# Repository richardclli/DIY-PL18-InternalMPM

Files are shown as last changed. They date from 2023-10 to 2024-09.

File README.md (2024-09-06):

# DIY-PL18-InternalMPM
An internal MPM (Multi-Protocol Module) for Flysky PL18 Mod

This internal module works with the modified version of Flysky PL18 that flashes with EdgeTX:

https://github.com/EdgeTX/edgetx/wiki/PL18-Hardware-Mod-for-Complete-EdgeTX-Support

For MPM firmware download, please visit the official page:

https://github.com/pascallanger/DIY-Multiprotocol-TX-Module

## Installation Procedures:
1. Add an antenna to the PL18

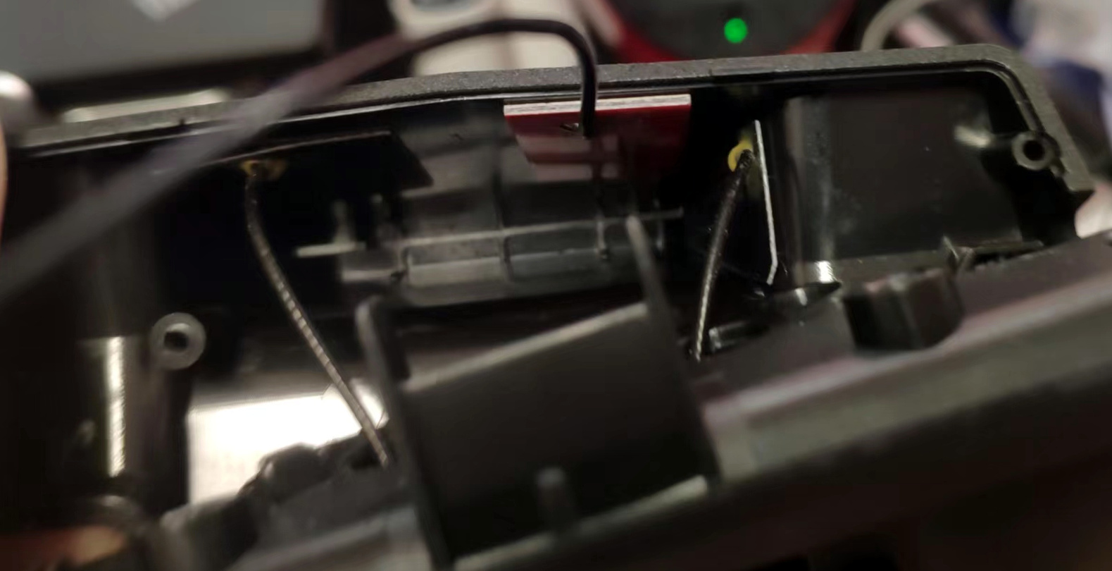
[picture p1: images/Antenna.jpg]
Antanna Installation


2. Solder the power control wire to PI.00 pin

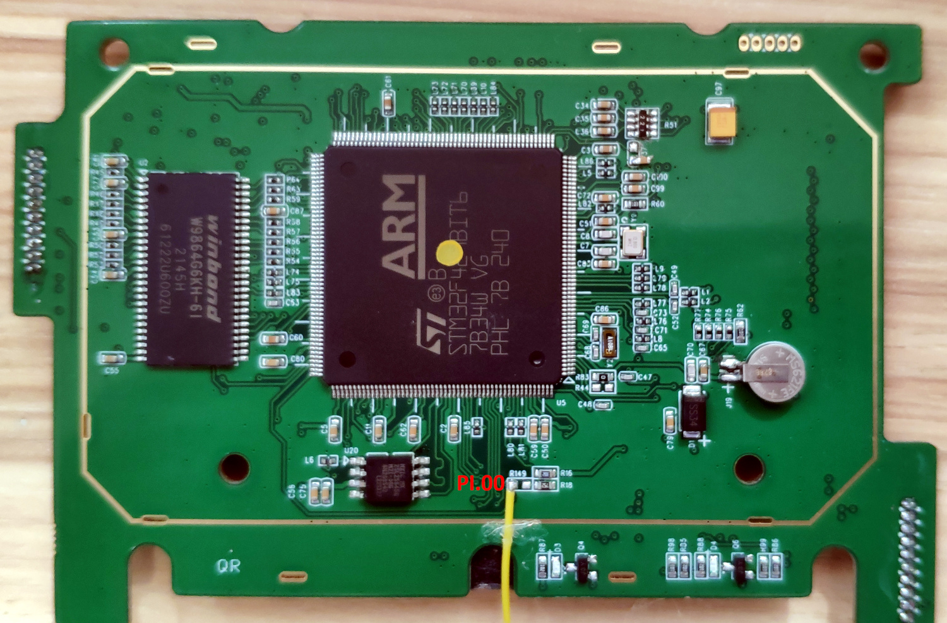
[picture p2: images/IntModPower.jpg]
Add Power Control


3. Install the PCB and insert the power control pin, you may need to use a sticky tape to ensure the MPM PCB is fixed to the PL18 PCB properly.

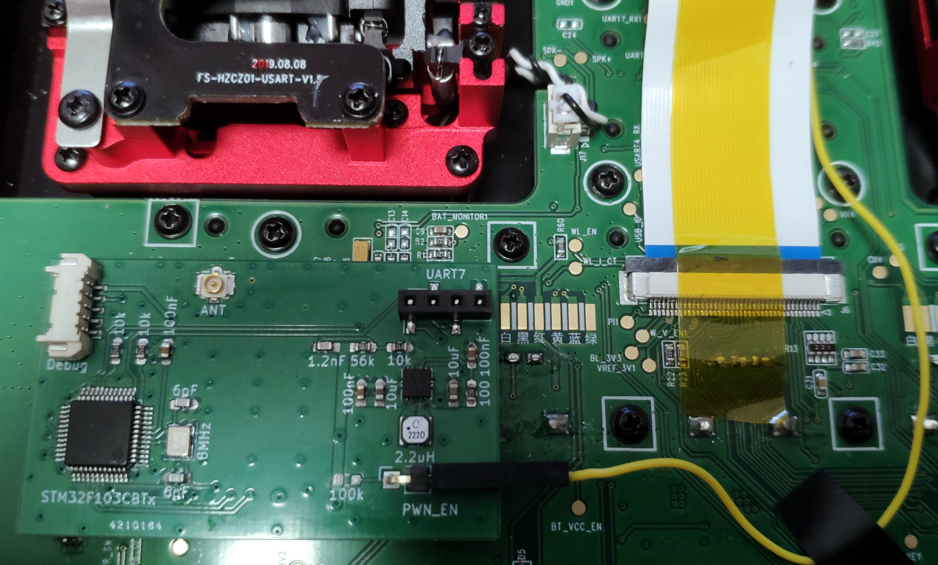
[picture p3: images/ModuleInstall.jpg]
Install PCB


Note:
The 100k pull up resistor for the power control pin is for testing purpose, it DO NOT NEED to be soldered as per the images shown.

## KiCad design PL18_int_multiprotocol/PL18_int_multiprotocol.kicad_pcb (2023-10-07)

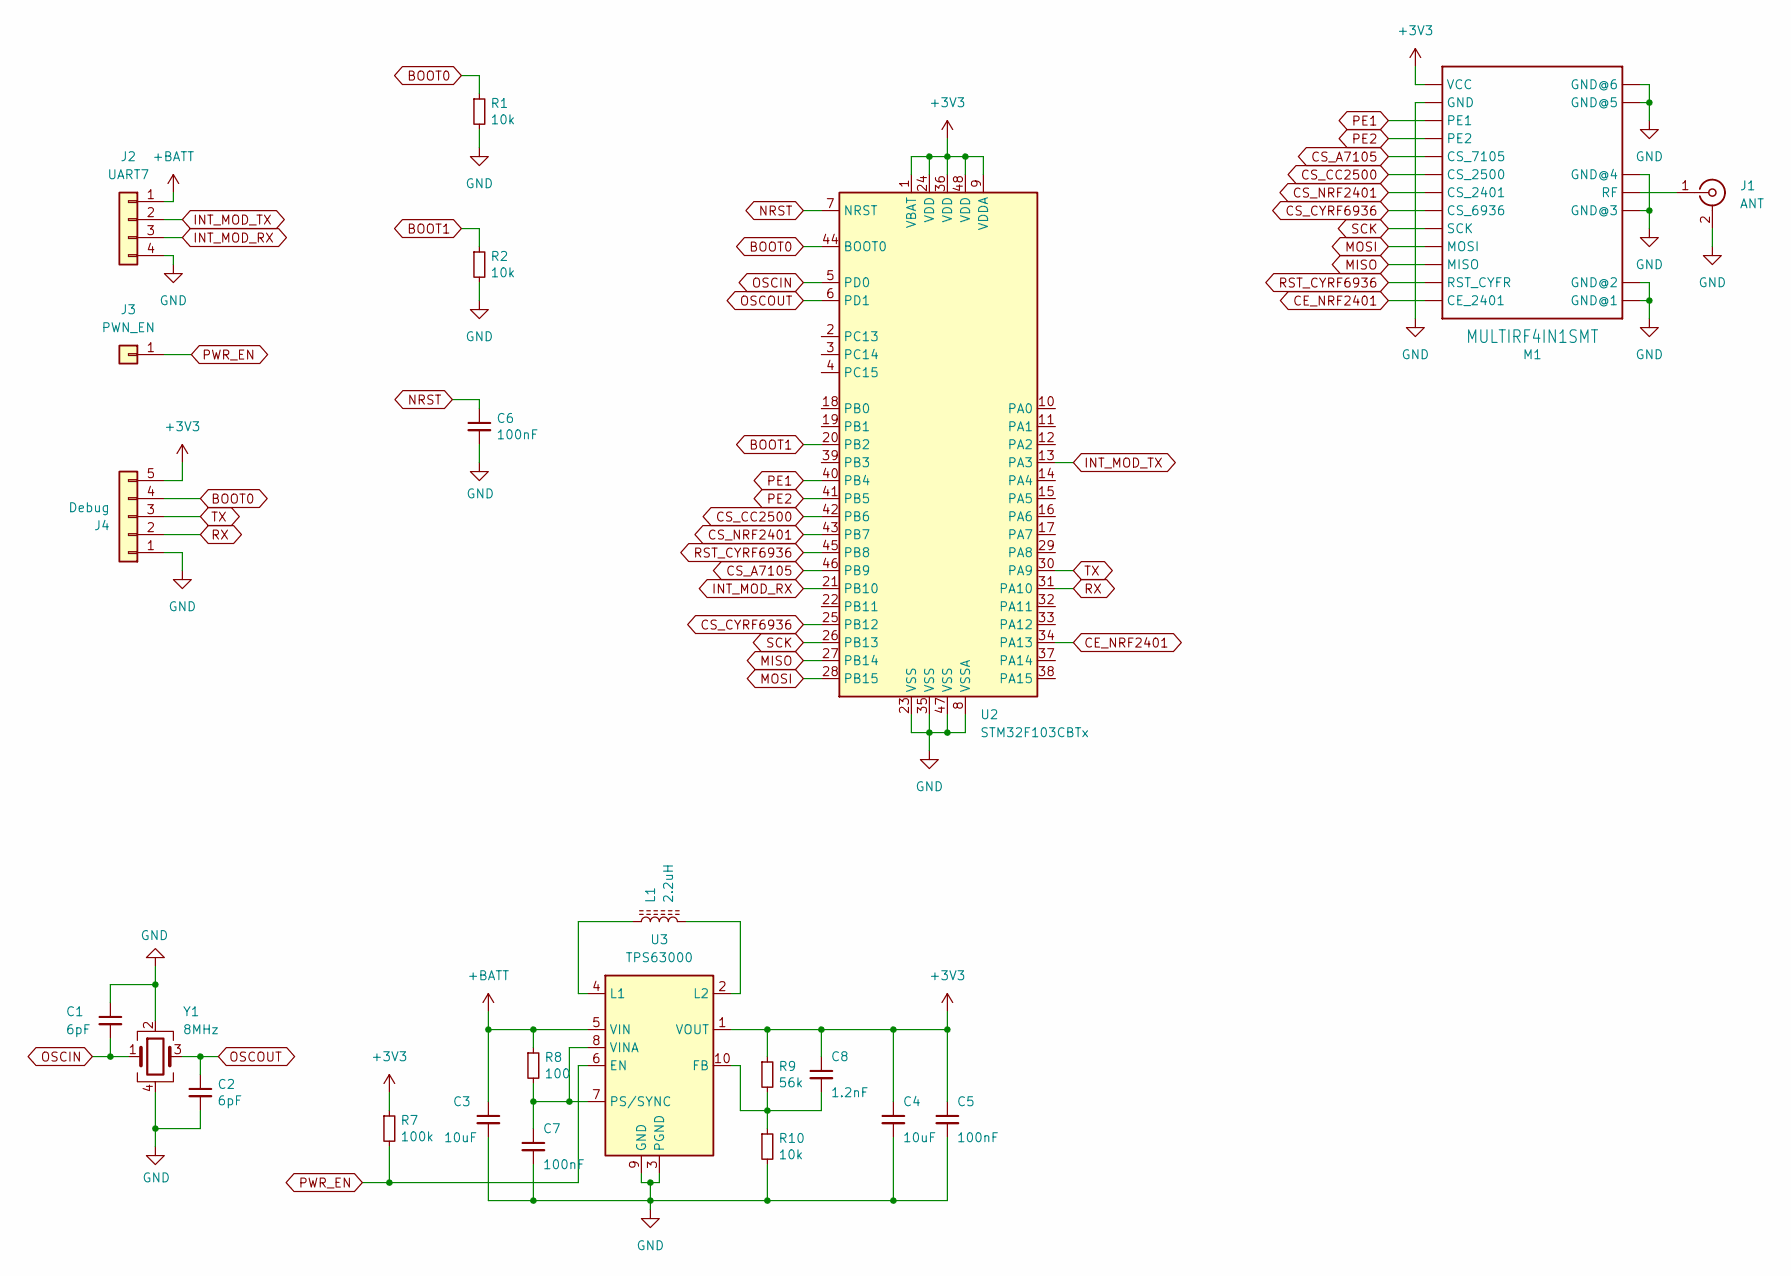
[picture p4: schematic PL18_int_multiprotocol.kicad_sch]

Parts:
C1, C2: 6pF; C_0603_1608Metric_Pad1.08x0.95mm_HandSolder
C3, C4: 10uF; C_0603_1608Metric_Pad1.08x0.95mm_HandSolder
C5, C6, C7: 100nF; C_0603_1608Metric_Pad1.08x0.95mm_HandSolder
C8: 1.2nF; C_0603_1608Metric_Pad1.08x0.95mm_HandSolder
J1: ANT; U.FL_Molex_MCRF_73412-0110_Vertical
J2: UART7; PinHeader_1x04_P2.54mm_Vertical_SMD_Pin1Left_Holes
J3: PWN_EN; PinHeader_1x01_P2.54mm_Horizontal
J4: Debug; JST_GH_BM05B-GHS-TBT_1x05-1MP_P1.25mm_Vertical
L1: 2.2uH; L_Abracon_ASPI-3012S
M1: MULTIRF4IN1SMT; MULTIRF4IN1-SMT
R1, R2, R10: 10k; R_0603_1608Metric_Pad0.98x0.95mm_HandSolder
R7: 100k; R_0603_1608Metric_Pad0.98x0.95mm_HandSolder
R8: 100; R_0603_1608Metric_Pad0.98x0.95mm_HandSolder
R9: 56k; R_0603_1608Metric_Pad0.98x0.95mm_HandSolder
U2: STM32F103CBTx; LQFP-48_7x7mm_P0.5mm
U3: TPS63000; Texas_DRC0010J_ThermalVias
Y1: 8MHz; Oscillator_SMD_Abracon_ASE-4Pin_3.2x2.5mm

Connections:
+3V3: C4.1, C5.1, C8.1, J4.5, M1.VCC, R7.1, R9.1, U2.1 (VBAT), U2.9 (VDDA), U2.24 (VDD), U2.36 (VDD), U2.48 (VDD), U3.1 (VOUT)
+BATT: C3.1, J2.1, R8.1, U3.5 (VIN)
BOOT0: J4.4, R1.1, U2.44 (BOOT0)
BOOT1: R2.1, U2.20 (PB2)
CE_NRF2401: M1.CE_2401, U2.34 (PA13)
CS_A7105: M1.CS_7105, U2.46 (PB9)
CS_CC2500: M1.CS_2500, U2.42 (PB6)
CS_CYRF6936: M1.CS_6936, U2.25 (PB12)
CS_NRF2401: M1.CS_2401, U2.43 (PB7)
GND: C1.1, C2.2, C3.2, C4.2, C5.2, C6.2, C7.2, J1.2 (Ext), J2.4, J4.1, M1.GND, M1.GND@1, M1.GND@2, M1.GND@3, M1.GND@4, M1.GND@5, M1.GND@6, R1.2, R2.2, R10.2, U2.8 (VSSA), U2.23 (VSS), U2.35 (VSS), U2.47 (VSS), U3.3 (PGND), U3.9 (GND), U3.11 (PGND), Y1.2, Y1.4
INT_MOD_RX: J2.3, U2.21 (PB10)
INT_MOD_TX: J2.2, U2.13 (PA3)
MISO: M1.MISO, U2.27 (PB14)
MOSI: M1.MOSI, U2.28 (PB15)
NRST: C6.1, U2.7 (NRST)
unnamed: C7.1, R8.2, U3.7 (PS/SYNC), U3.8 (VINA)
unnamed: C8.2, R9.2, R10.1, U3.10 (FB)
unnamed: J1.1 (In), M1.RF
unnamed: L1.1, U3.4 (L1)
unnamed: L1.2, U3.2 (L2)
OSCIN: C1.2, U2.5 (PD0), Y1.1
OSCOUT: C2.1, U2.6 (PD1), Y1.3
PE1: M1.PE1, U2.40 (PB4)
PE2: M1.PE2, U2.41 (PB5)
PWR_EN: J3.1, R7.2, U3.6 (EN)
RST_CYRF6936: M1.RST_CYFR, U2.45 (PB8)
RX: J4.2, U2.31 (PA10)
SCK: M1.SCK, U2.26 (PB13)
TX: J4.3, U2.30 (PA9)

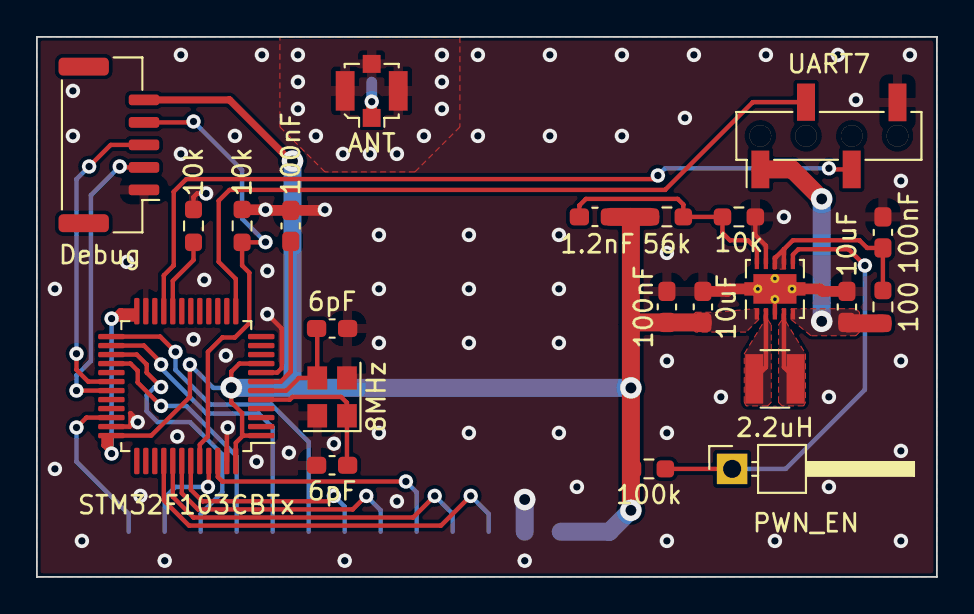
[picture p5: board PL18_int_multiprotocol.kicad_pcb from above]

Board: 2 copper layers, 50.0 x 30.0 mm, 23 parts (1 on the bottom side), 29 nets.
